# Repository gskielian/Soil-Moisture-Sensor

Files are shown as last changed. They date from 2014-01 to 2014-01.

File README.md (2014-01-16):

Soil-Moisture-Sensors
=====================

I'll be designing a lot of these it seems.

##Description of Circuits

```bash
.
├── 555_Astable_SMS
│   ├── 555_resistance_sensor.fzz
│   ├── 555_resistance_sensor.png
│   ├── README.md
│   └── Soil_Moisture_Sensor.ino
└── Voltage_Divider_SMS
    ├── dataFile.txt
    ├── soil_moisture_poll.ino
    └── soil_moisture_poll.py

```
### Voltage Divider Circuit
So far my favorite is the Voltage Divider, as it is simple to wire, and straightforward to measure (simple analogRead).

### The 555-Astable circuit

This circuit measures using the hardware-interrupt.
we are also seemingly limited by the size of a volatile int (best to set it at the negative end and then count up from that to get the full range -- unsigned int doesn't seem to change anything even though it compiles)

### The 555-One Shot circuit

The Equation is `1.1 * R * C = pulse duration`.  This can be easily measured using the pulseIn() function in Arduino, and also yields a convenient method for calculating the precise resistance and capacitance.

I think this circuit will become my favorite after building it.

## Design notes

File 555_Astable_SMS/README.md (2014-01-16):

Soil-Moisture-Sensor
====================

This is a schematic and code for creating a 555 based soil-moisture-sensor based on the resistance of the soil.

Because this depends on the frequency of oscillation, we can increase our sensor's sensitivity by **decreasing** the overall resistance.

## Schematic

<p align="center">
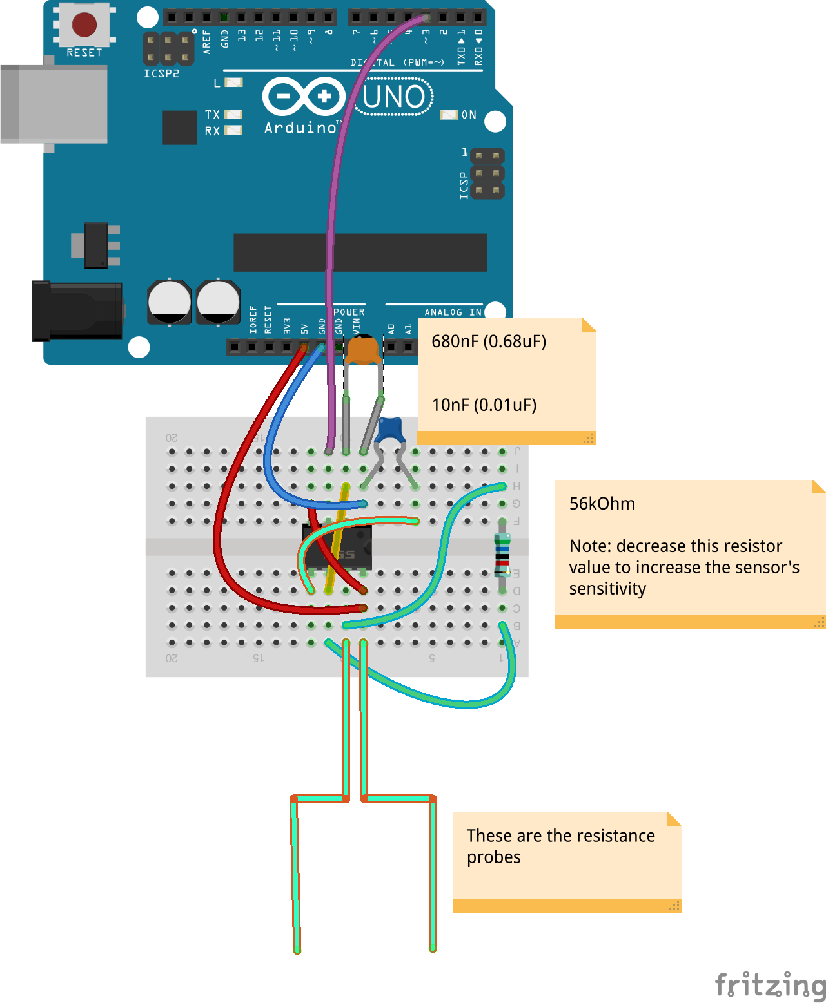
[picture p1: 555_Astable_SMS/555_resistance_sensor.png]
fritzing diagram

</p>

## BOM

| Amount | Part  |
| :--- |  :--- |
| 1 | 0.68 nF (680pF) Ceramic Capacitor |
| 1 | 10 nF (0.01uF) Ceramic Capacitor |
| 1 | 56kOhm Resistor |
| 1 | 555 Timer |

## Code

The code relies on hardware interrupts, and they are different pins on different models.

Here is a linke to the Arduino Site for interrupt pins and documentation:
http://arduino.cc/en/Reference/attachInterrupt

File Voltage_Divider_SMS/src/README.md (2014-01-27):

Soil-Moisture-Sensor Voltage Divider
====================================

There were two major challenges we faced when creating a robust sensor:
* **hysteresis**  and
* **probe corrosion**

### Hysteresis
The voltage divider had it's initial difficulties with hysteresis.  Apparently measuring water's resistance changed the resistance of the water measured (I speculate this may be due to the ion redistribution effects from the metal probe's electric fields), one of the consequences of this is our readout would never setlle -- the resistance was coupled to the previous state.

To remedy this, I reset the pinmodes and then wait around 500ms between measurements to both "drain" excess charge from each pin and to allow the water to return to it's initial state.

After implementing this we definitively removed readout drift! 

### Probe Corrosion

To keep our measurements in the linear range of the voltage divider, we first match our soil's resistance with a metal-film resistor (which usually turns out to be around 30kOhms, but varies with your probe setup).

#### Hardware Innovation 

Typical current-based soil moisture sensors tend to corrode fairly quicky if their metals are exposed to the elements.  Some groups attempt to reduce corrosion of their sensor through electroplating with less corrosion prone metals like gold. 

As per our mission to make this technology accessible, our strategy was to find corrosion resistant materials which are available in common hardware stores and inexpensive -- which is why we experimented (successfully!) with galvanized nails.*  So far this has worked like a charm!

*Whole of the credit for this critical innovation goes to [treeherder](https://github.com/treeherder).

#### Software Innovation

The second innovation for addressing probe corrosion was to to minimize the time when electricity is flowing from one probe to the other.  This is the second awesome feature of our solution for the hysteresis problem, as all pins are in the ground state between measurements!

### Future directions

In order to ensure greater reliability, we could switch to a current sensing method an employ an op-amp.  This would allow us to ramp the overall resistance of the circuit, and minimize the amount of electricity which flows through the water during measurements.  However, I doubt that anything will beat the simplicty of this method.

##Description of Circuits

```bash
.
├── 555_Astable_SMS
│   ├── 555_resistance_sensor.fzz
│   ├── 555_resistance_sensor.png
│   ├── README.md
│   └── Soil_Moisture_Sensor.ino
└── Voltage_Divider_SMS
    ├── dataFile.txt
    ├── soil_moisture_poll.ino
    └── soil_moisture_poll.py

```
### Voltage Divider Circuit
So far my favorite is the Voltage Divider, as it is simple to wire, and straightforward to measure (simple analogRead).

### The 555-Astable circuit

This circuit measures using the hardware-interrupt.
we are also seemingly limited by the size of a volatile int (best to set it at the negative end and then count up from that to get the full range -- unsigned int doesn't seem to change anything even though it compiles)

### The 555-One Shot circuit

The Equation is `1.1 * R * C = pulse duration`.  This can be easily measured using the pulseIn() function in Arduino, and also yields a convenient method for calculating the precise resistance and capacitance.

I think this circuit will become my favorite after building it.

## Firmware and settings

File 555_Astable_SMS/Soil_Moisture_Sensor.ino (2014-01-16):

//a potentiometer may be used in place of the 56KOhm 
//as a hardware sensitivity dial

volatile long int count=0; // volatile allows it to be changed by the interrupt function

int accumulation_time=10000; //in microseconds

void setup() {
  Serial.begin(9600);

  //interrupt 1 is pin 3 on the Uno
  //attachInterrup(interrupt number, function-to-call, RISING/FALLING/CHANGE)

  attachInterrupt(1, add_to_count, CHANGE);
}

void loop() {

//reset the counter
  count=0;
//allow the counter to accumulate -- higher resistance means more clicks
  delayMicroseconds(accumulation_time);
//print
Serial.println(count);

}

void add_to_count() {
 count++;
}

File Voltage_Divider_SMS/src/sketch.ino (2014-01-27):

char ch;
void setup() {
  Serial.begin(115200);
}


void loop() {

  if (Serial.available()) {
    ch = Serial.read();
    if (ch == '1') {
      forward_measurement();
    } else if (ch == '2') {
      reverse_measurement();
    } else {
      delay(1);
    }
  }

}




void forward_measurement() {

//FIRST we set all pins to 0V to remove hysterisis

pinMode(14, OUTPUT);
digitalWrite(14,LOW);
pinMode(16,OUTPUT);
digitalWrite(16,LOW);
pinMode(18, OUTPUT);
digitalWrite(18, LOW);

delay(200);

//SECOND we make the voltage divider

//16 to be an input
pinMode(16, INPUT);

//we set 14 and 18 (aka a0 and a4) to outputs
pinMode(14, OUTPUT);
digitalWrite(14,HIGH);

pinMode(18, OUTPUT);
digitalWrite(18,LOW);

//NEXT we poll for voltage reading
delay(500);
Serial.print("Forward Measurement, "); Serial.println(analogRead(A2));


}


void reverse_measurement() {

  Serial.println("testing pre measurement");
  Serial.println(analogRead(1));

  //FIRST we make the voltage divider

  //16 to be an input (not really necessary the first time)
  pinMode(16, INPUT);

  //we set 14 and 18 (aka a0 and a4) to outputs
  pinMode(14, OUTPUT);
  digitalWrite(14,LOW);

  pinMode(18, OUTPUT);
  digitalWrite(18,HIGH);

  //NEXT we poll for voltage reading
  delay(500);
  Serial.print("Reverse_Measurement"); Serial.println(1023-analogRead(1));

  //LAST we set all pins to 0V to remove hysterisis

  digitalWrite(18,LOW);
  pinMode(16,OUTPUT);
  digitalWrite(16,LOW);

  //again a python delay of one second goes after this
}

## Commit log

2014-01-10 adjusted readme and reorganized
    [555_resistance_sensor.fzz, DC_Sensor_Fritzing_Schematic.fzz]
2014-01-10 added the 555 and resistor to the BOM
2014-01-10 added documentation to the arduino sketch
2014-01-10 added updated fzz and png
    [555_resistance_sensor.fzz]
2014-01-10 removed blurb from schematic
2014-01-16 added reverse and forwards measurement
    it seems that adding forward and reverse
    measurement helps.
    There might be some hysterisis in the water
    in addition to hysterisis in the accumulated
    charge.
2014-01-16 refactored directory structure, added Readme
    [555_resistance_sensor.fzz]
2014-01-16 began compilation with the **ino** it's great!
    [555_resistance_sensor.fzz]
2014-01-16 added a lot of work on one shot -- please help!
    one shot is not working, it seems that
    I will need to set the pulseIn before the
    timer goes off.
    On the other hand I know that the one shot
    is going off, as I can easily place an
    led there.
    I could probably place another arduino there
    just to see if it would work though
    [sketch.cpp, sketch.ino, soil_moisture_poll.py]
2014-01-27 fixed the voltage divider code
    [sketch.ino, soil_moisture_poll.py]
